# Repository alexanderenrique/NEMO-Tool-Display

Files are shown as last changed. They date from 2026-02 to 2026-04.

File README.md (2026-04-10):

# NEMO Tool Display

IoT system with ESP32 displays that show real-time tool status from the NEMO backend system. Displays show who is using tools, usage duration, and tool operational status.

## Quick Start

### 1. VM Server Setup
```bash
cd vm-server
./setup.sh
```

The setup script will:
- Install and configure Mosquitto MQTT broker
- Set up Python virtual environment with dependencies
- Generate an HMAC key for NEMO↔broker authentication (broker only accepts signed messages when set)
- Start MQTT broker and NEMO server

### 2. ESP32 Configuration
Edit `display-firmware/src/config.h` with your WiFi SSID/password, MQTT broker and credentials, and tool name (e.g. `TARGET_TOOL_NAME`).

**⚠️ SECURITY WARNING:** Never commit real WiFi credentials, MQTT passwords, or IP addresses to version control!

### 3. Upload Firmware
```bash
cd display-firmware && pio run -t upload
```

## Hardware Connections

**TFT Display (480x320):**
```
ESP32 Pin  →  Display Pin
GPIO 23    →  MOSI
GPIO 18    →  SCLK
GPIO 5     →  CS
GPIO 17    →  DC
GPIO 16    →  RST
3.3V       →  VCC
GND        →  GND
```
T_IRQ
T_DO (Touch MISO) = 32
T_DIN = 26
T_CS = 33
T_CLK = 25
MISO
LED
SCK = 25
MOSI = 26
DC/RS = 27
RESET = 14
CS  = 13
GND
VCC

## Configuration

The system uses **centralized configuration** to ensure consistency between ESP32 and VM server:

### Centralized Configuration System
- **`display-firmware/src/config.h`** - Single configuration file (WiFi, MQTT, tool, display; not overridden by build flags)
- **`vm-server/config_parser.py`** - Python parser that reads from `display-firmware/src/config.h`
- **`NEMO_CONFIG_H`** (optional) - Absolute path to `config.h` when the firmware tree is not at `display-firmware/` beside `vm-server/`

### VM Server (config.env)
```env
# MQTT Configuration
MQTT_BROKER=your_mqtt_broker_ip   # Replace with your VM server's IP
MQTT_PORT=1886                    # NEMO backend port (VM server only)
MQTT_USERNAME=
MQTT_PASSWORD=

# Display Configuration
TIMEZONE_OFFSET_HOURS=-7
MAX_NAME_LENGTH=13
LOG_LEVEL=INFO
```

### ESP32 (display-firmware/src/config.h)
All ESP32 settings (WiFi, MQTT broker/port/credentials, tool ID/name, display) are in `display-firmware/src/config.h`. When broker authentication is enabled on the VM server, set `MQTT_USERNAME` and `MQTT_PASSWORD` in `display-firmware/src/config.h` to match `vm-server/config.env`.

### Port Configuration
- **ESP32 Port (1883)**: Used by ESP32 displays to receive status updates
- **NEMO Port (1886)**: Used by VM server to receive messages from NEMO backend
- **Configuration**: ESP32 port in `display-firmware/src/config.h`, NEMO port in `config.env`

Tool names are provided in MQTT messages from NEMO; no separate tool lookup or mapping file is required.

## MQTT Topics

**Backend Input (from NEMO):**
- `nemo/backend/tools/{tool_id}/status` - Individual tool status
- `nemo/backend/tools/overall` - Overall system status

**ESP32 Output (to displays):**
- `nemo/esp32/{tool_id}/status` - Tool status for specific display (uses tool ID for routing)
- `nemo/esp32/overall` - Overall status for all displays

**Server Status:**
- `nemo/server/status` - VM server health status

## Message Format

### Tool Status Message
```json
{
  "id": "113",
  "name": "woollam",
  "status": "active",
  "category": "Exfab",
  "operational": true,
  "problematic": false,
  "timestamp": "2025-01-15T10:30:00",
  "user": {
    "name": "John Doe",
    "username": "johndoe",
    "id": 80
  },
  "usage": {
    "start_time": "2025-01-15T10:30:00",
    "start_time_formatted": "Jan 15, 2025 at 10:30 AM",
    "usage_id": 12345
  }
}
```

### Overall Status Message
```json
{
  "total_tools": 199,
  "active_tools": 15,
  "available_tools": 180,
  "problematic_tools": 4,
  "timestamp": "2025-01-15T10:30:00"
}
```

### HMAC (NEMO↔broker)
When `MQTT_HMAC_KEY` is set in `config.env`, the VM server only accepts messages that include a valid HMAC. The broker (VM server) rejects any message without a correct signature. ESP32 traffic (port 1883) is not HMAC-protected.

**Envelope format when HMAC is enabled:** NEMO must publish:
```json
{"payload": "<original payload string>", "hmac": "<hex signature>", "algo": "sha256"}
```
- **payload**: The exact original payload string (e.g. JSON as a string). This is the string that was signed—same formatting/whitespace, no re-serialization.
- **hmac**: HMAC of that payload string, hex-encoded. Computed as `HMAC(secret_key, payload)` with key = shared secret (UTF-8), message = payload string (UTF-8), algorithm from `algo`.
- **algo**: Digest algorithm, e.g. `sha256` (default if omitted).

Verification uses the same secret (UTF-8), hashes the `payload` string as-is (UTF-8), and compares the hex digest with `hmac` using constant-time comparison. If HMAC is not required, leave `MQTT_HMAC_KEY` empty; then the server accepts normal (unwrapped) payloads.

## Setup Process Details

### VM Server Setup Steps
1. **Configuration Validation** - Checks for required files
2. **Install Mosquitto** - MQTT broker installation
3. **Stop Existing Processes** - Clean shutdown of running services
4. **Clean Configuration** - Remove old config and log files
5. **Create Mosquitto Config** - Generate broker configuration
6. **Test Configuration** - Verify MQTT functionality
7. **Set Up Python Environment** - Create venv and install dependencies
8. **Generate Tool Mappings** - Fetch tools from NEMO API
9. **Set Up Environment File** - Create config.env and generate HMAC key
10. **Start MQTT Broker** - Launch Mosquitto
11. **Start NEMO Server** - Launch Python application

### ESP32 Setup Steps
1. **Configure WiFi** - Set SSID and password in `display-firmware/src/config.h`
2. **Configure MQTT** - Set broker IP and port in `display-firmware/src/config.h`
3. **Set Tool Name** - Specify which tool this display shows
4. **Upload Firmware** - Compile and flash to ESP32

## Troubleshooting

### ESP32 Issues
**Can't connect to WiFi:**
- Check WiFi credentials in `display-firmware/src/config.h`
- Verify network is 2.4GHz (ESP32 doesn't support 5GHz)
- Check signal strength

**Can't connect to MQTT:**
- Verify MQTT broker IP address in `display-firmware/src/config.h`
- Check MQTT port (1883 for ESP32, 1886 for NEMO backend)
- Ensure ESP32 and server are on same network
- Check MQTT broker IP and port match the server

**Display not working:**
- Check wiring connections (see Hardware Connections)
- Verify TFT_eSPI library is installed
- Monitor serial output: `pio device monitor`

### VM Server Issues
**MQTT broker won't start:**
- Check logs: `tail -f vm-server/mqtt/log/mosquitto.log`
- Verify ports 1883 and 1886 are not in use
- Check Mosquitto configuration: `mosquitto -c mqtt/config/mosquitto.conf -v`

**NEMO server issues:**
- Check Python dependencies: `pip install -r requirements.txt`
- Verify configuration in `config.env`
- Run comprehensive tests: `python3 test_system.py`
- Test MQTT: `mosquitto_sub -h localhost -t "nemo/#" -v`

**NEMO backend MQTT "unauthorized" (rc=5) or connection timeout:**
- The NEMO Django app (nemo-ce-alex) must use the **same** broker, port, username, and password as `vm-server/config.env`. Set NEMO's MQTT settings to match: `MQTT_BROKER` (use the machine IP where Mosquitto runs, or `localhost` if NEMO and Mosquitto run on the same host), `MQTT_PORT=1886`, `MQTT_USERNAME` and `MQTT_PASSWORD` identical to config.env.
- **Unauthorized (rc=5)**: Username/password in NEMO do not match the broker's password file. Re-run `vm-server/setup.sh` to set broker auth, then copy the printed MQTT config into NEMO's MQTT settings.
- **Connection timeout to localhost:1886**: Mosquitto may not be running, or NEMO is pointing at the wrong host. Start the broker (e.g. `vm-server/quick_restart.sh` or start Mosquitto manually) and ensure NEMO's broker host is correct. When VM server or mqtt_monitor starts, they print the current MQTT config for verification.

### Network Issues
**ESP32 can't reach server:**
- Ensure both devices are on same network
- Check firewall settings on VM server
- Verify MQTT broker is listening on correct interface
- Test with: `mosquitto_pub -h SERVER_IP -t "test" -m "hello"`

## Monitoring and Debugging

### Available Scripts

#### Setup Script (`setup.sh`)
Complete system setup and configuration:
```bash
cd vm-server
./setup.sh
```

**What it does:**
- Installs Mosquitto MQTT broker
- Sets up Python virtual environment
- Creates MQTT configuration
- Starts all services

#### Quick Restart Script (`quick_restart.sh`)
Fast restart for development:
```bash
cd vm-server
./quick_restart.sh
```

**What it does:**
1. Stops all existing MQTT broker and server processes
2. Clears MQTT ports (1883, 1886)
3. Starts Mosquitto MQTT broker on both ports
4. Starts the NEMO server (vm-server/main.py)

#### Test Script (`test_system.py`)
Comprehensive system testing:
```bash
cd vm-server
python3 test_system.py
```

**What it tests:**
- System processes (MQTT broker, NEMO server)
- Port connectivity (1883, 1886)
- Message parsing and trimming logic
- MQTT connections (NEMO and ESP32)
- End-to-end functionality

#### MQTT Monitor (`mqtt_monitor.py`)
Real-time MQTT traffic monitoring:
```bash
cd vm-server
python3 mqtt_monitor.py
```

**Features:**
- Monitors MQTT ports (1883 and NEMO port from config)
- Shows message direction and content
- Displays connection status
- Real-time traffic analysis

**⚠️ Important - Internal Development Setup:**
When running the actual NEMO application and this display system on the same machine, restarting Mosquitto will temporarily break NEMO's MQTT connection:

1. **During restart:** NEMO's connection to Mosquitto is severed
2. **Message impact:** Messages published during the restart may be lost or queued
3. **Reconnection:** NEMO's MQTT plugin typically auto-reconnects once Mosquitto is back up

**Best Practice:** Avoid restarting Mosquitto during active tool usage. For production deployments, run the MQTT broker on a separate machine to prevent this issue.

### MQTT Monitoring
```bash
# Monitor all NEMO topics
mosquitto_sub -h localhost -t "nemo/#" -v

# Monitor specific tool
mosquitto_sub -h localhost -t "nemo/esp32/woollam/status" -v

# Monitor server status
mosquitto_sub -h localhost -t "nemo/server/status" -v

# Use the comprehensive monitor script
cd vm-server
python3 mqtt_monitor.py
```

### Log Files
- **MQTT Broker:** `vm-server/mqtt/log/mosquitto.log`
- **NEMO Server:** Console output or `nemo_server.log`
- **ESP32:** Serial monitor output

### Testing MQTT
```bash
# Publish test message
mosquitto_pub -h localhost -t "nemo/test" -m "test message"

# Subscribe to test
mosquitto_sub -h localhost -t "nemo/test" -v
```

## Project Structure

```
├── vm-server/                    # Python server and configuration
│   ├── main.py                  # Main NEMO server application
│   ├── setup.sh                 # Complete system setup script
│   ├── quick_restart.sh         # Fast restart for development
│   ├── test_system.py           # Comprehensive system tests
│   ├── mqtt_monitor.py          # MQTT traffic monitor
│   ├── config_parser.py         # Centralized config parser
│   ├── config.env              # Server configuration
│   ├── requirements.txt        # Python dependencies
│   ├── mqtt/                   # MQTT broker files
│   │   ├── config/mosquitto.conf
│   │   ├── data/               # Persistence data
│   │   └── log/                # Log files
│   └── venv/                   # Python virtual environment
├── display-firmware/               # PlatformIO / ESP32 firmware
│   ├── src/main.cpp            # ESP32 firmware
│   ├── src/config.h            # ESP32 configuration (single source)
│   ├── include/lv_conf.h        # LVGL configuration
│   ├── lib/                    # ESP32 libraries
│   └── platformio.ini           # Build configuration
├── tool-display-pcb/             # KiCad project, gerbers; backups/ holds zip snapshots
└── README.md                   # This file
```

## Security Notes

### 🔒 **CRITICAL SECURITY REQUIREMENTS**

1. **Never commit real credentials to version control:**
   - WiFi SSID and password in `display-firmware/src/config.h`
   - MQTT broker IP addresses
   - NEMO API tokens in `config.env`
   - Any other sensitive configuration

2. **Use environment variables or local config files:**
   - Keep `config.env` in `.gitignore` (already configured)
   - Use placeholder values in committed files
   - Set real values locally for development

3. **API Token Security:**
   - Keep your NEMO token secure and don't commit it to version control
   - Use strong, unique tokens
   - Rotate tokens regularly

4. **MQTT Security:**
   - HMAC is between the NEMO backend and the VM server (broker): when `MQTT_HMAC_KEY` is set, the server only accepts messages with a valid HMAC and rejects others.
   - NEMO sends: `{"payload": "<exact payload string>", "hmac": "<hex>", "algo": "sha256"}`. The signed value is the exact `payload` string (UTF-8); key is the shared secret (UTF-8). No re-serialization or trimming.
   - Restrict broker access with firewall rules

5. **Network Security:**
   - Use VPN or firewall rules to restrict access to MQTT broker
   - Consider using private networks for IoT devices
   - Monitor network traffic for anomalies

### 🛡️ **Security Checklist**
- [ ] All real credentials removed from committed files
- [ ] `config.env` is in `.gitignore` and not tracked
- [ ] Placeholder values used in example configurations
- [ ] MQTT broker secured with authentication (if needed)
- [ ] Network access restricted appropriately
- [ ] Regular security updates applied

## Contributing

1. Fork the repository
2. Create a feature branch
3. Make your changes
4. Test thoroughly
5. Submit a pull request

## License

[Add your license information here]

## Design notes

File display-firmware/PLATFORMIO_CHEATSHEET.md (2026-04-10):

# PlatformIO Cheat Sheet

Quick reference for common PlatformIO CLI commands in the project root.

pio run -t clean
pio run -t upload
pio device monitor

## Build & run

| Command | Description |
|---|---|
| `pio run` | Build the project (compile only) |
| `pio run -t upload` | Build and upload firmware to the device |
| `pio run -t upload -e esp32dev` | Build and upload for a specific environment |

## Clean

| Command | Description |
|---|---|
| `pio run -t clean` | Remove build artifacts (`.pio/build/`) for current env |
| `pio run -t fullclean` | Deep clean (build dirs + tool cache for this project) |
| `pio run -t compiledb` | Regenerate `compile_commands.json` for clangd / IDE (file is gitignored) |

## Device & monitor

| Command | Description |
|---|---|
| `pio device list` | List connected serial ports / boards |
| `pio device monitor` | Open serial monitor (default 9600 baud) |
| `pio device monitor -b 115200` | Serial monitor at 115200 baud |
| `pio run -t upload && pio device monitor` | Upload then open monitor |

## Environments

| Command | Description |
|---|---|
| `pio run -e esp32dev` | Build for environment `esp32dev` (see `platformio.ini`) |
| `pio run -e env1 -e env2` | Build for multiple environments |

## Libraries & dependencies

| Command | Description |
|---|---|
| `pio pkg install` | Install dependencies from `platformio.ini` |
| `pio pkg update` | Update installed libraries |
| `pio lib list` | List libraries used by the project |

## Shortcuts

- **Build:** `pio run`
- **Clean:** `pio run -t clean`
- **Upload:** `pio run -t upload`
- **Monitor:** `pio device monitor`

Run `pio run -t help` for all targets (e.g. `uploadfs`, `size`, etc.) for the current environment.

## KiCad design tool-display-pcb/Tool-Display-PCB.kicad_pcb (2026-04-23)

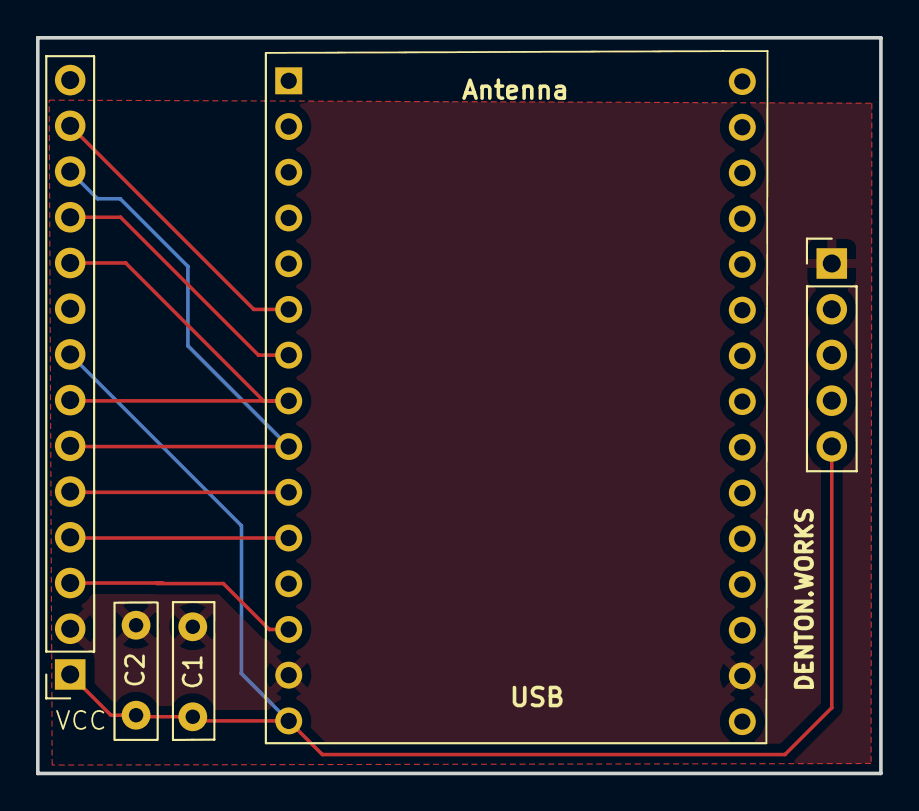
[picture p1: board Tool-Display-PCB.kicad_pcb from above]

Board: 2 copper layers, 46.8 x 40.9 mm, 5 parts (0 on the bottom side), 9 nets.

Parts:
C1, C2: C_Small_US; C_Disc_D7.5mm_W4.4mm_P5.00mm
J1: 4" TFT SPI DISPLAY; TFT-14pin-Alex
J2: ESP32 30-Pin; ESP32-C3-30pin-Alex
J4: Conn_01x05_Pin; Alex-5pin-microUSB

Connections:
GND: C1.1, C2.1, J1.GND (Pin_2), J2.GND (Pin_2), J4.GND (Pin_1)
unnamed: C1.2, C2.2, J1.LED (Pin_8), J1.VCC (Pin_1), J2.VIN (3.3), J4.VIN (Pin_5)
unnamed: J1.CS (Pin_3), J2.13 (Pin_3)
unnamed: J1.RST (Pin_4), J2.14 (Pin_5)
unnamed: J1.DC (Pin_5), J2.27 (Pin_6)
unnamed: J1.SCK (Pin_7), J1.T_CLK (Pin_10), J2.25 (Pin_8)
unnamed: J1.MOSI (Pin_6), J1.T_DIN (Pin_12), J2.26 (Pin_7)
unnamed: J1.T_CS, J2.33 (Pin_9)
unnamed: J1.T_DO, J2.32 (Pin_10)

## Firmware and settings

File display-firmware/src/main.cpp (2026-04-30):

/*
 * NEMO Tool Display - Simple Test
 * Basic WiFi connection and LVGL display test
 */

#include <WiFi.h>
#include <TFT_eSPI.h>
#include <SPI.h>
#include <lvgl.h>
#include <PubSubClient.h>
#include <ArduinoJson.h>
#include "config.h"
#include "hardware.h"


// MQTT topics - use tool ID and prefix from build flags
String mqtt_topic_status = String(MQTT_TOPIC_PREFIX) + "/" + String(TARGET_TOOL_ID) + "/status";
String mqtt_topic_operational = String(MQTT_TOPIC_PREFIX) + "/" + String(TARGET_TOOL_ID) + "/operational";
String mqtt_topic_task = String(MQTT_TOPIC_PREFIX) + "/" + String(TARGET_TOOL_ID) + "/task";
String mqtt_topic_next_reservation = String(MQTT_TOPIC_PREFIX) + "/" + String(TARGET_TOOL_ID) + "/next_reservation";
String mqtt_topic_overall = String(MQTT_TOPIC_PREFIX) + "/overall";

// State: tool_operational from .../operational only; task topic updates task store + UI copy only
bool tool_operational = true;
bool has_task = false;
String task_summary = "";       // Derived from task store (aggregated)
String problem_description = ""; // Derived from task store (aggregated)
bool last_status_enabled = false;  // From last status message; used for border when operational

// Multiple-task store (ESP32 tracks per task_id; VM sends one event per message)
#define MAX_TASKS 6
#define MAX_SUMMARY_LEN 200
#define MAX_DESCRIPTION_LEN 600
struct TaskEntry {
  int64_t id;
  bool used;
  String summary;
  String description;
};
static TaskEntry s_tasks[MAX_TASKS];

static void taskStoreAddOrUpdate(int64_t taskId, const String& summary, const String& description);
static void taskStoreRemove(int64_t taskId);
static void taskStoreClearAll();
static bool taskStoreHasAny();
static int taskStoreCount();
static String taskStoreGetAggregatedSummary();
static String taskStoreGetAggregatedDescription();

// Display configuration (TFT 480x320)
TFT_eSPI tft = TFT_eSPI();

// MQTT client
WiFiClient wifiClient;
PubSubClient mqttClient(wifiClient);

// LVGL display buffer
static lv_disp_draw_buf_t draw_buf;
static lv_color_t buf[480 * 10]; // 10 lines buffer

// LVGL display driver
static lv_disp_drv_t disp_drv;

// LVGL UI elements
lv_obj_t *title_label = nullptr;
lv_obj_t *status_label = nullptr;
lv_obj_t *user_label = nullptr;
lv_obj_t *user_value = nullptr;
lv_obj_t *time_label = nullptr;
lv_obj_t *time_value = nullptr;
lv_obj_t *outer_ring = nullptr;             // Outer ring: yellow = task, none/white = no task
lv_obj_t *status_indicator = nullptr;       // Inner ring: green = enabled, red = disabled
lv_obj_t *normal_container = nullptr;       // Shown when tool is operational (red + white text when non-operational)
lv_obj_t *task_summary_label = nullptr;     // Task summary line, visible only when non-operational (same layout as status)
lv_obj_t *problem_description_label = nullptr;
lv_obj_t *details_container = nullptr;   // Details screen (problem description)
lv_obj_t *details_outer_ring = nullptr;
lv_obj_t *details_status_indicator = nullptr;
lv_obj_t *details_title_label = nullptr;
lv_obj_t *res_outer_ring = nullptr;
lv_obj_t *res_status_indicator = nullptr;
// Global navigation (always visible, bottom-right)
lv_obj_t *btn_nav_back = nullptr;        // Left arrow (back)
lv_obj_t *btn_nav_forward = nullptr;     // Right arrow (forward)

// Next reservation page (per-tool topic .../<TARGET_TOOL_ID>/next_reservation)
lv_obj_t *reservation_container = nullptr;
lv_obj_t *res_title_label = nullptr;
lv_obj_t *res_next_row_lbl = nullptr;
lv_obj_t *res_next_row_val = nullptr;
lv_obj_t *res_time_row_lbl = nullptr;
lv_obj_t *res_time_row_val = nullptr;
lv_obj_t *res_empty_label = nullptr;
bool reservation_has_booking = false;
String reservation_booking_user = "";
String reservation_start_text = "";
String reservation_end_text = "";
String reservation_time_range_text = "";
int lookahead_days_reserved = 7;

// Screen state / auto-timeout (reservation + problems screens return to status after idle)
static unsigned long secondary_screen_shown_at = 0;
static const unsigned long SECONDARY_SCREEN_TIMEOUT_MS = 30000UL;

enum ScreenId { SCREEN_STATUS = 0, SCREEN_DETAILS = 1, SCREEN_RESERVATION = 2 };
static ScreenId current_screen = SCREEN_STATUS;

// Tool name from config
String toolDisplayName = "";

// Function declarations
void setupWiFi();
void setupMQTT();
void connectMQTT();
void mqttCallback(char* topic, byte* payload, unsigned int length);
void processMQTTMessage(const char* topic, const char* payload);
void my_disp_flush(lv_disp_drv_t *disp, const lv_area_t *area, lv_color_t *color_p);
void touch_read(lv_indev_drv_t *indev_drv, lv_indev_data_t *data);
void create_simple_ui();
String toolNameForDisplay(const char* toolName);
void updateConnectionStatus();
void updateStatusIndicator(bool isEnabled);  // Inner ring: enabled (green) / disabled (red)
void updateOuterRing(bool hasTask);          // Outer ring: yellow if task, else none
void applyMainScreenState();  // Show/hide normal vs non-operational, set both rings
void show_status_screen();   // Show status view, hide details
void show_details_screen();  // Show details view, hide status
void show_reservation_screen();
static void navigate_forward();
static void navigate_back();
void refreshReservationWidgets();
void applyNextReservationMQTT(JsonDocument& doc);

void setup() {
  Serial.begin(9600);
  Serial.println("NEMO Tool Display - Simple Test Starting...");
  
  // Initialize tool display name from config until MQTT provides tool_name (same as NEMO: no reformatting)
  toolDisplayName = toolNameForDisplay(TARGET_TOOL_NAME);
  Serial.print("Tool Display Name: ");
  Serial.println(toolDisplayName);
  
  // Initialize MQTT topics with tool ID and prefix from build flags
  mqtt_topic_status = String(MQTT_TOPIC_PREFIX) + "/" + String(TARGET_TOOL_ID) + "/status";
  mqtt_topic_operational = String(MQTT_TOPIC_PREFIX) + "/" + String(TARGET_TOOL_ID) + "/operational";
  mqtt_topic_task = String(MQTT_TOPIC_PREFIX) + "/" + String(TARGET_TOOL_ID) + "/task";
  mqtt_topic_next_reservation = String(MQTT_TOPIC_PREFIX) + "/" + String(TARGET_TOOL_ID) + "/next_reservation";
  Serial.print("MQTT Status Topic: ");
  Serial.println(mqtt_topic_status);
  Serial.print("MQTT Operational Topic: ");
  Serial.println(mqtt_topic_operational);
  Serial.print("MQTT Task Topic: ");
  Serial.println(mqtt_topic_task);
  Serial.print("MQTT next_reservation: ");
  Serial.println(mqtt_topic_next_reservation);

  // Initialize TFT display
  tft.init();
  tft.setRotation(DISPLAY_ROTATION); // Use rotation from build flags
  tft.fillScreen(TFT_WHITE);
  
  // Initialize LVGL
  lv_init();
  
  // Initialize display buffer
  lv_disp_draw_buf_init(&draw_buf, buf, NULL, DISPLAY_WIDTH * 10);
  
  // Initialize display driver
  lv_disp_drv_init(&disp_drv);
  disp_drv.hor_res = DISPLAY_WIDTH;
  disp_drv.ver_res = DISPLAY_HEIGHT;
  disp_drv.flush_cb = my_disp_flush;
  disp_drv.draw_buf = &draw_buf;
  lv_disp_drv_register(&disp_drv);
  
  // Initialize touch input device for LVGL
  static lv_indev_drv_t indev_drv;
  lv_indev_drv_init(&indev_drv);
  indev_drv.type = LV_INDEV_TYPE_POINTER;
  indev_drv.read_cb = touch_read;
  lv_indev_drv_register(&indev_drv);
  Serial.println("Touch input enabled (pointer)");
  
  // Create simple UI
  create_simple_ui();
  
  // Enable WiFi and MQTT so we can show live connection status on the display
  setupWiFi();
  setupMQTT();
  updateConnectionStatus();
  
  Serial.println("Touch input registered with LVGL (T_CS=33)");
  Serial.println("Setup complete - WiFi/MQTT status mode");
}

void loop() {
  // Update LVGL timer (5ms)
  lv_tick_inc(5);
  
  // Handle LVGL tasks
  lv_timer_handler();
  
  // Maintain WiFi/MQTT connectivity and update status label
  {
    static unsigned long lastWifiAttempt = 0;
    static unsigned long lastMqttAttempt = 0;
    static unsigned long lastStatusUpdate = 0;
    static bool linkLogInit = false;
    static bool prevWifiUp = false;
    static bool prevMqttUp = false;
    unsigned long now = millis();

    const bool wifiUp = (WiFi.status() == WL_CONNECTED);
    const bool mqttUp = mqttClient.connected();
    if (!linkLogInit) {
      prevWifiUp = wifiUp;
      prevMqttUp = mqttUp;
      linkLogInit = true;
    } else {
      if (wifiUp != prevWifiUp) {
        Serial.print(now);
        Serial.print(" ms [link] WiFi ");
        Serial.println(wifiUp ? "CONNECTED" : "DISCONNECTED");
      }
      if (mqttUp != prevMqttUp) {
        Serial.print(now);
        Serial.print(" ms [link] MQTT ");
        Serial.print(mqttUp ? "CONNECTED" : "DISCONNECTED");
        if (mqttUp)
          Serial.println(" (broker may deliver retained operational/task/status next)");
        else
          Serial.println();
      }
      prevWifiUp = wifiUp;
      prevMqttUp = mqttUp;
    }

    // Periodically try to (re)connect WiFi if not connected
    if (WiFi.status() != WL_CONNECTED) {
      if (now - lastWifiAttempt >= WIFI_RECONNECT_INTERVAL) {
        lastWifiAttempt = now;
        Serial.println("WiFi not connected, attempting periodic reconnection...");
        WiFi.disconnect();
        WiFi.begin(ssid, password);
      }
    }
    
    // Periodically try to (re)connect MQTT if WiFi is up
    if (WiFi.status() == WL_CONNECTED && !mqttClient.connected()) {
      if (now - lastMqttAttempt >= MQTT_RECONNECT_INTERVAL) {
        lastMqttAttempt = now;
        connectMQTT();
      }
    }
    
    // Run MQTT client loop when connected
    if (mqttClient.connected()) {
      mqttClient.loop();
    }
    
    // Periodically refresh the consolidated WiFi/MQTT status label
    if (now - lastStatusUpdate >= DISPLAY_UPDATE_INTERVAL) {
      lastStatusUpdate = now;
      updateConnectionStatus();
    }

    // Auto-return to enable/disable screen after 30s on reservation or problems
    if (current_screen != SCREEN_STATUS &&
        (now - secondary_screen_shown_at >= SECONDARY_SCREEN_TIMEOUT_MS)) {
      Serial.println("Secondary screen timeout, returning to status screen");
      show_status_screen();
    }
  }


  delay(5); // Reduced delay for LVGL responsiveness
}

void setupWiFi() {
  Serial.println("Starting WiFi connection...");
  Serial.print("SSID: ");
  Serial.println(ssid);
  
  updateConnectionStatus();
  
  WiFi.begin(ssid, password);
  
  int attempts = 0;
  int maxAttempts = WIFI_CONNECT_TIMEOUT / 500; // Convert timeout to attempts
  while (WiFi.status() != WL_CONNECTED && attempts < maxAttempts) {
    delay(500);
    Serial.print(".");
    attempts++;
    
    // Update status every 5 attempts
    if (attempts % 5 == 0) {
      Serial.print(" (attempt ");
      Serial.print(attempts);
      Serial.println(")");
    }
  }
  
  if (WiFi.status() == WL_CONNECTED) {
    Serial.println("");
    Serial.println("WiFi connected successfully!");
    Serial.print("IP address: ");
    Serial.println(WiFi.localIP());
    Serial.print("Signal strength: ");
    Serial.print(WiFi.RSSI());
    Serial.println(" dBm");
    
    updateConnectionStatus();
  } else {
    Serial.println("");
    Serial.println("WiFi connection failed!");
    Serial.print("Status: ");
    Serial.println(WiFi.status());
    
    updateConnectionStatus();
  }
}


// LVGL display flush function
void my_disp_flush(lv_disp_drv_t *disp, const lv_area_t *area, lv_color_t *color_p) {
  uint32_t w = (area->x2 - area->x1 + 1);
  uint32_t h = (area->y2 - area->y1 + 1);
  
  tft.startWrite();
  tft.setAddrWindow(area->x1, area->y1, w, h);
  tft.pushColors((uint16_t*)&color_p->full, w * h, true);
  tft.endWrite();
  
  lv_disp_flush_ready(disp);
}

// Touch input read callback for LVGL
void touch_read(lv_indev_drv_t *indev_drv, lv_indev_data_t *data) {
  uint16_t x = 0, y = 0;
  bool touched = false;
#ifdef TOUCH_CS
  touched = tft.getTouch(&x, &y);
#endif
  static bool was_pressed = false;
  if (touched) {
    if (x >= DISPLAY_WIDTH) x = DISPLAY_WIDTH - 1;
    if (y >= DISPLAY_HEIGHT) y = DISPLAY_HEIGHT - 1;
    // Touch controller Y is inverted vs LVGL display: physical top reports low Y.
    // Invert Y so touching the visual button position matches LVGL's bottom-right.
    data->point.x = x;
    data->point.y = (DISPLAY_HEIGHT - 1) - y;
    data->state = LV_INDEV_STATE_PRESSED;
    if (!was_pressed) {
      Serial.print("Touch: pressed at (");
      Serial.print(x);
      Serial.print(", ");
      Serial.print(y);
      Serial.println(")");
      was_pressed = true;
    }
  } else {
    data->state = LV_INDEV_STATE_RELEASED;
    data->point.x = 0;
    data->point.y = 0;
    if (was_pressed) {
      Serial.println("Touch: released");
      was_pressed = false;
    }
  }
}

static String reservationScreenTitleText() {
  return String("Next User");
}

static String detailsScreenTitleText() {
  return String("Problems");
}

static void applySecondaryScreenTitles() {
  if (res_title_label)
    lv_label_set_text(res_title_label, reservationScreenTitleText().c_str());
  if (details_title_label)
    lv_label_set_text(details_title_label, detailsScreenTitleText().c_str());
}

// Create LVGL UI: status view only (no tabs)
void create_simple_ui() {
  const uint32_t backgroundColor = 0xFFFFFF;
  const uint32_t textColor = 0x000000;
  const lv_font_t* titleFont = &lv_font_montserrat_48;
  const lv_font_t* statusFont = &lv_font_montserrat_16;
  const lv_font_t* labelFont = &lv_font_montserrat_16;
  const lv_font_t* valueFont = &lv_font_montserrat_32;
  const int screenMargin = 8;
  const int outerRingWidth = 14;
  const int innerRingWidth = 20;
  const int outerW = DISPLAY_WIDTH - 2 * screenMargin;
  const int outerH = DISPLAY_HEIGHT - 2 * screenMargin;
  const int innerW = outerW - 2 * outerRingWidth;
  const int innerH = outerH - 2 * outerRingWidth;
  const int arrowSize = 48;
  const int arrowMargin = 12;
  const int arrowGap = 10;
  const int contentPad = 8;
  const int textAreaW = innerW - 2 * contentPad;

  lv_obj_t *screen = lv_scr_act();

  // ---- Tab 0: Status ----
  // Normal container (white interior, two rings, user/time labels)
  normal_container = lv_obj_create(screen);
  lv_obj_set_size(normal_container, DISPLAY_WIDTH, DISPLAY_HEIGHT);
  lv_obj_set_pos(normal_container, 0, 0);
  lv_obj_set_style_bg_color(normal_container, lv_color_hex(backgroundColor), 0);
  lv_obj_set_style_border_width(normal_container, 0, 0);
  lv_obj_set_style_pad_all(normal_container, 0, 0);
  lv_obj_set_scrollbar_mode(normal_container, LV_SCROLLBAR_MODE_OFF);

  // Outer ring: always same size so inner content never shifts. Yellow when task, background color when no task.
  outer_ring = lv_obj_create(normal_container);
  lv_obj_set_size(outer_ring, outerW, outerH);
  lv_obj_set_pos(outer_ring, screenMargin, screenMargin);
  lv_obj_set_style_bg_opa(outer_ring, LV_OPA_TRANSP, 0);  // No fill – only border is visible
  lv_obj_set_style_border_width(outer_ring, outerRingWidth, 0);  // Always same width – updateOuterRing() only changes color
  lv_obj_set_style_border_color(outer_ring, lv_color_hex(backgroundColor), 0);  // Invisible until task (yellow)
  lv_obj_set_style_radius(outer_ring, 0, 0);
  lv_obj_set_style_pad_all(outer_ring, 0, 0);
  lv_obj_set_style_outline_width(outer_ring, 0, 0);
  lv_obj_set_scrollbar_mode(outer_ring, LV_SCROLLBAR_MODE_OFF);
  lv_obj_clear_flag(outer_ring, LV_OBJ_FLAG_SCROLLABLE);

  // Inner ring: green = enabled, red = disabled. Flush with outer ring so only two rings show.
  status_indicator = lv_obj_create(outer_ring);
  lv_obj_set_size(status_indicator, innerW, innerH);
  lv_obj_set_pos(status_indicator, 0, 0);  // Flush to outer ring content area – no gap
  lv_obj_set_style_bg_color(status_indicator, lv_color_hex(0xFFFFFF), 0);
  lv_obj_set_style_border_width(status_indicator, innerRingWidth, 0);
  lv_obj_set_style_border_color(status_indicator, lv_color_hex(0x00FF00), 0);
  lv_obj_set_style_radius(status_indicator, 0, 0);
  lv_obj_set_style_pad_all(status_indicator, contentPad, 0);
  lv_obj_set_style_outline_width(status_indicator, 0, 0);
  lv_obj_set_scrollbar_mode(status_indicator, LV_SCROLLBAR_MODE_OFF);
  lv_obj_clear_flag(status_indicator, LV_OBJ_FLAG_SCROLLABLE);

  title_label = lv_label_create(status_indicator);
  lv_label_set_text(title_label, toolDisplayName.c_str());
  lv_obj_set_style_text_font(title_label, titleFont, 0);
  lv_obj_set_style_text_color(title_label, lv_color_hex(textColor), 0);
  lv_obj_align(title_label, LV_ALIGN_TOP_LEFT, 0, 0);

  user_label = lv_label_create(status_indicator);
  lv_label_set_text(user_label, "User");
  lv_obj_set_style_text_font(user_label, labelFont, 0);
  lv_obj_set_style_text_color(user_label, lv_color_hex(textColor), 0);
  lv_obj_align(user_label, LV_ALIGN_TOP_LEFT, 0, 65);

  user_value = lv_label_create(status_indicator);
  lv_label_set_text(user_value, "--");
  lv_obj_set_style_text_font(user_value, valueFont, 0);
  lv_obj_set_style_text_color(user_value, lv_color_hex(textColor), 0);
  lv_obj_align(user_value, LV_ALIGN_TOP_LEFT, 0, 82);

  time_label = lv_label_create(status_indicator);
  lv_label_set_text(time_label, "Enabled/Disabled Since");
  lv_obj_set_style_text_font(time_label, labelFont, 0);
  lv_obj_set_style_text_color(time_label, lv_color_hex(textColor), 0);
  lv_obj_align(time_label, LV_ALIGN_TOP_LEFT, 0, 140);

  time_value = lv_label_create(status_indicator);
  lv_label_set_text(time_value, "--:--");
  lv_obj_set_style_text_font(time_value, valueFont, 0);
  lv_obj_set_style_text_color(time_value, lv_color_hex(textColor), 0);
  lv_obj_align(time_value, LV_ALIGN_TOP_LEFT, 0, 162);

  status_label = lv_label_create(status_indicator);
  lv_label_set_text(status_label, "Initializing...");
  lv_obj_set_style_text_font(status_label, statusFont, 0);
  lv_obj_set_style_text_color(status_label, lv_color_hex(textColor), 0);
  lv_obj_align(status_label, LV_ALIGN_BOTTOM_LEFT, 0, 0);

  // Task summary line (same layout as status; visible only when non-operational, between title and User)
  task_summary_label = lv_label_create(status_indicator);
  lv_label_set_text(task_summary_label, "");
  lv_obj_set_style_text_font(task_summary_label, valueFont, 0);
  lv_obj_set_style_text_color(task_summary_label, lv_color_hex(0xFFFFFF), 0);
  lv_obj_align(task_summary_label, LV_ALIGN_TOP_LEFT, 0, 48);
  lv_label_set_long_mode(task_summary_label, LV_LABEL_LONG_WRAP);
  lv_obj_add_flag(task_summary_label, LV_OBJ_FLAG_HIDDEN);  // Shown only when non-operational

  // Global navigation arrows (always visible, bottom-right)
  btn_nav_forward = lv_btn_create(screen);
  lv_obj_set_size(btn_nav_forward, arrowSize, arrowSize);
  lv_obj_align(btn_nav_forward, LV_ALIGN_BOTTOM_RIGHT, -arrowMargin, -arrowMargin);
  lv_obj_set_style_radius(btn_nav_forward, arrowSize / 2, 0);
  lv_obj_t *lbl_fwd = lv_label_create(btn_nav_forward);
  lv_label_set_text(lbl_fwd, LV_SYMBOL_RIGHT);
  lv_obj_center(lbl_fwd);
  lv_obj_add_event_cb(btn_nav_forward, [](lv_event_t *e) { navigate_forward(); }, LV_EVENT_CLICKED, NULL);

  btn_nav_back = lv_btn_create(screen);
  lv_obj_set_size(btn_nav_back, arrowSize, arrowSize);
  lv_obj_align(btn_nav_back, LV_ALIGN_BOTTOM_RIGHT, -(arrowMargin + arrowSize + arrowGap), -arrowMargin);
  lv_obj_set_style_radius(btn_nav_back, arrowSize / 2, 0);
  lv_obj_t *lbl_bk = lv_label_create(btn_nav_back);
  lv_label_set_text(lbl_bk, LV_SYMBOL_LEFT);
  lv_obj_center(lbl_bk);
  lv_obj_add_event_cb(btn_nav_back, [](lv_event_t *e) { navigate_back(); }, LV_EVENT_CLICKED, NULL);

  // Next reservation screen (same ring chrome + title layout as status screen)
  reservation_container = lv_obj_create(screen);
  lv_obj_set_size(reservation_container, DISPLAY_WIDTH, DISPLAY_HEIGHT);
  lv_obj_set_pos(reservation_container, 0, 0);
  lv_obj_set_style_bg_color(reservation_container, lv_color_hex(backgroundColor), 0);
  lv_obj_set_style_border_width(reservation_container, 0, 0);
  lv_obj_set_style_pad_all(reservation_container, 0, 0);
  lv_obj_set_scrollbar_mode(reservation_container, LV_SCROLLBAR_MODE_OFF);
  lv_obj_add_flag(reservation_container, LV_OBJ_FLAG_HIDDEN);

  res_outer_ring = lv_obj_create(reservation_container);
  lv_obj_set_size(res_outer_ring, outerW, outerH);
  lv_obj_set_pos(res_outer_ring, screenMargin, screenMargin);
  lv_obj_set_style_bg_opa(res_outer_ring, LV_OPA_TRANSP, 0);
  lv_obj_set_style_border_width(res_outer_ring, outerRingWidth, 0);
  lv_obj_set_style_border_color(res_outer_ring, lv_color_hex(backgroundColor), 0);
  lv_obj_set_style_radius(res_outer_ring, 0, 0);
  lv_obj_set_style_pad_all(res_outer_ring, 0, 0);
  lv_obj_set_style_outline_width(res_outer_ring, 0, 0);
  lv_obj_set_scrollbar_mode(res_outer_ring, LV_SCROLLBAR_MODE_OFF);
  lv_obj_clear_flag(res_outer_ring, LV_OBJ_FLAG_SCROLLABLE);

  res_status_indicator = lv_obj_create(res_outer_ring);
  lv_obj_set_size(res_status_indicator, innerW, innerH);
  lv_obj_set_pos(res_status_indicator, 0, 0);
  lv_obj_set_style_bg_color(res_status_indicator, lv_color_hex(0xFFFFFF), 0);
  lv_obj_set_style_border_width(res_status_indicator, innerRingWidth, 0);
  lv_obj_set_style_border_color(res_status_indicator, lv_color_hex(0x00FF00), 0);
  lv_obj_set_style_radius(res_status_indicator, 0, 0);
  lv_obj_set_style_pad_all(res_status_indicator, contentPad, 0);
  lv_obj_set_style_outline_width(res_status_indicator, 0, 0);
  lv_obj_set_scrollbar_mode(res_status_indicator, LV_SCROLLBAR_MODE_OFF);
  lv_obj_clear_flag(res_status_indicator, LV_OBJ_FLAG_SCROLLABLE);

  res_title_label = lv_label_create(res_status_indicator);
  lv_label_set_text(res_title_label, reservationScreenTitleText().c_str());
  lv_obj_set_style_text_font(res_title_label, titleFont, 0);
  lv_obj_set_style_text_color(res_title_label, lv_color_hex(textColor), 0);
  lv_obj_set_width(res_title_label, textAreaW);
  lv_label_set_long_mode(res_title_label, LV_LABEL_LONG_WRAP);
  lv_obj_align(res_title_label, LV_ALIGN_TOP_LEFT, 0, 0);
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

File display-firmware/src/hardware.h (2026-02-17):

/*
 * NEMO Tool Display - Hardware configuration
 * Single source of truth for TFT and pins. Track this file between workspaces.
 * TFT_eSPI uses this when USER_SETUP_LOADED is defined (via platformio.ini -include).
 */

#ifndef HARDWARE_H
#define HARDWARE_H

/* Tell TFT_eSPI to use our defines instead of User_Setup.h */
#define USER_SETUP_LOADED
#define USER_SETUP_INFO "hardware.h"

/* -----------------------------------------------------------------------------
 * Display driver (only one uncommented)
 * ILI9341 = 240x320 typical; ILI9488 = 480x320 typical
 * ----------------------------------------------------------------------------- */
// #define ILI9341_DRIVER
#define ILI9488_DRIVER

/* -----------------------------------------------------------------------------
 * ESP32 SPI pins (from README pinout)
 * Display: SCK=25, MOSI=26, DC/RS=27, RESET=14, CS=13
 * Touch:   T_DO (MISO)=32, T_DIN (MOSI)=26, T_CS=33, T_CLK=25, T_IRQ not specified
 * ----------------------------------------------------------------------------- */

 //T_IRQ not used
 #define TFT_MISO 32   // T_DO
 //T_DIN = 26, TFT_MOSI = 26
#define TOUCH_CS  33  // T_CS
//T_CLK = 25
//TFT_MISO = 32
//LED
#define TFT_SCLK 25
#define TFT_MOSI 26   // T_DIN
#define TFT_DC    27  /* Data/Command (DC/RS) */
#define TFT_RST   14  /* Reset */
#define TFT_CS    13  /* Chip select */
//GND
//VCC

#define SPI_TOUCH_FREQUENCY  2500000  /* XPT2046 max ~2.5MHz; required for touch */

/* XPT2046 calibration (480x320) - adjust if touch is off; use TFT_eSPI Touch_calibrate sketch to find values */
#define XPT2046_X_MIN     200
#define XPT2046_X_MAX     3800
#define XPT2046_Y_MIN     200
#define XPT2046_Y_MAX     3800

/* SPI transactions required for ESP32 to switch between TFT and touch on shared bus */
#define SUPPORT_TRANSACTIONS

/* -----------------------------------------------------------------------------
 * SPI frequency (Hz)
 * ----------------------------------------------------------------------------- */
#define SPI_FREQUENCY       27000000
#define SPI_READ_FREQUENCY  16000000

/* -----------------------------------------------------------------------------
 * Fonts to load (comment out to save flash)
 * ----------------------------------------------------------------------------- */
#define LOAD_GLCD
#define LOAD_FONT2
#define LOAD_FONT4
#define LOAD_FONT6
#define LOAD_FONT7
#define LOAD_FONT8
#define LOAD_GFXFF
#define SMOOTH_FONT

#endif /* HARDWARE_H */

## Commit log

2025-09-04 working through the API, filtering
2025-09-18 vm broker config, tool specific publication
    [main.cpp]
2025-09-21 Add white background/black text UI, dynamic IP setup, and ESP32 improvements
    - Updated ESP32 display to white background with black text for better readability
    - Added configurable color variables in create_simple_ui() function
    - Implemented dynamic IP detection and configuration for VM server
    - Added first/last name display support in MQTT messages
    - Created dynamic IP setup scripts and documentation
    - Fixed platformio.ini configuration for proper LVGL compilation
    - Updated MQTT configuration to use centralized config.h
    - Added comprehensive setup and restart scripts with IP detection
    - Improved error handling and debug output
    - Added documentation for simplified IP configuration approach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
    [main.cpp]
2026-02-17 touch works
    [Tool-Display-PCB.kicad_pcb, Tool-Display-PCB.kicad_sch]
2026-02-18 PCB changes
    [Tool-Display-PCB.kicad_pcb, Tool-Display-PCB.kicad_sch]
2026-02-19 pcb finished, shipped
    [Tool-Display-PCB-B_Cu.gbr, Tool-Display-PCB-B_Mask.gbr, Tool-Display-PCB-B_Paste.gbr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]
2026-02-26 ESP32 cleanup and reconcile
2026-03-01 chore: remove secrets from repo — add config.h.example and .env.example, gitignore config.h
    Made-with: Cursor
2026-04-09 tool naming, max user name length, mysterious state bug
    [main.cpp]
2026-04-10 big refactor and polish
    [Tool-Display-PCB-B_Cu.gbr, Tool-Display-PCB-B_Mask.gbr, Tool-Display-PCB-B_Paste.gbr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]
2026-04-23 PCB updates, narrower, additional USB option
    [Tool-Display-PCB.kicad_pcb, Tool-Display-PCB.kicad_sch]
